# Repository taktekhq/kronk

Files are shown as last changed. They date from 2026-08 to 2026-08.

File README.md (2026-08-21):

# kronk

DIY Raspberry Pi video intercom. Pull the lever, Kronk!

Someone rings the building gate. You see them, talk to them, and buzz them in from your home.

First hardware project, documented in public so anyone can build one.

## Docs

| Doc | Content |
|---|---|
| [Parts](docs/parts.md) | What you need, and what I got |
| [Bill](docs/bill.csv) | What I paid |
| [Gate setup](docs/gate-setup.md) | Setting up `kronk-gate`, step by step |
| [Home setup](docs/home-setup.md) | Setting up the Pi 5 with Home Assistant |
| [Build log](docs/build-log.md) | Progress journal |
| [Architecture](docs/architecture.md) | How it fits together |

## Status

The gate camera is live in Apple Home with audio, recording, and face recognition. The doorbell button and lock relay are on MQTT. Home Assistant entities, HomeKit, and the speaker are next.

## License

[MIT](LICENSE)

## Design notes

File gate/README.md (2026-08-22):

# kronk-gate daemon

Bridges the gate GPIO to MQTT.

| Event | Topic | Payload |
|---|---|---|
| Button press, GPIO27 | `kronk/doorbell` | `ding` |
| Unlock command | `kronk/lock/set` | `UNLOCK` |
| Lock state, retained | `kronk/lock/state` | `UNLOCKED`, then `LOCKED` after the 3s relay pulse on GPIO17 |
| Daemon state, retained | `kronk/status` | `online`, `offline` |

Retained messages on `kronk/lock/set` are ignored and cleared. A retained `UNLOCK` would replay on every reconnect. Publish commands without the retain flag.

## Build

Tag `gate-v*`. The [release workflow](../.github/workflows/release-gate.yml) attaches `kronk-gate-arm64` to the GitHub Release.

Local cross compile:

```
GOOS=linux GOARCH=arm64 CGO_ENABLED=0 go build -trimpath -ldflags "-s -w" -o kronk-gate-arm64 .
```

## Deploy

Create `/home/nizarmah/kronk-gate.env` on the Pi. Single-quote the values, no single quotes inside.

```
KRONK_BROKER='tcp://homeassistant.local:1883'
KRONK_MQTT_USER='kronk-gate'
KRONK_MQTT_PASS='change-me'
```

The daemon resolves `.local` names itself, one mDNS query per connect attempt. The static build cannot use the system resolver, so a plain hostname lookup would die with `no such host`.

It holds the MQTT password, keep it owner-only:

```
chmod 600 ~/kronk-gate.env
```

Download the release binary and unit on the Pi, then enable:

```
curl -Lo kronk-gate https://github.com/taktekhq/kronk/releases/latest/download/kronk-gate-arm64
curl -LO https://raw.githubusercontent.com/taktekhq/kronk/main/gate/kronk-gate.service
chmod +x kronk-gate
sudo mv kronk-gate.service /etc/systemd/system/
sudo systemctl daemon-reload
sudo systemctl enable --now kronk-gate
```

Upgrading: `sudo systemctl stop kronk-gate` first. Writing into the running binary fails with `Text file busy`. Curl, then start the service again.

Manual run instead of the service:

```
set -a; . ~/kronk-gate.env; set +a; ~/kronk-gate
```

## Test

Home Assistant: Settings, Devices and services, MQTT, Configure, listen to `kronk/#`.

- Press the button: `kronk/doorbell` shows `ding`.
- Publish `UNLOCK` to `kronk/lock/set`, retain unchecked: the relay clicks for 3s, `kronk/lock/state` shows `UNLOCKED` then `LOCKED`.
- Stop the service: `kronk/status` shows `offline`.

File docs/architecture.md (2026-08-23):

# Architecture

Working plan, partially built. The [build log](build-log.md) tracks reality.

```
        BUILDING GATE                          APARTMENT
┌─────────────────────────────┐      ┌───────────────────────────────┐
│  Gate unit                  │      │  Indoor unit                  │
│                             │      │                               │
│  Raspberry Pi Zero 2 W      │ WiFi │  Raspberry Pi 5 (4GB)         │
│   ├─ Camera Module 3 NoIR   │◄────►│   ├─ Home Assistant           │
│   ├─ USB mini microphone    │      │   ├─ TDA7266 amp + speaker    │
│   ├─ Doorbell push button   │      │   └─ Microphone (TBD)         │
│   ├─ Relay → gate opener    │      │                               │
│   └─ 12V→5V buck converter  │      │                               │
└─────────────────────────────┘      └───────────────────────────────┘
```

## Software

- `kronk-gate` streams camera video and mic audio with [go2rtc](https://github.com/AlexxIT/go2rtc). Setup in [gate setup](gate-setup.md).
- The Pi 5 runs Home Assistant. Setup in [home setup](home-setup.md).
- Scrypted, a Home Assistant add-on, pulls the gate stream over RTSP and serves the camera to Apple Home as its own accessory. The camera does not go through Home Assistant.
- The HomeKit Bridge exposes the lock to Apple Home. The doorbell rings through Scrypted, a video doorbell on the camera.
- An Apple TV is the Home hub, which enables access over the internet.
- UI: the Apple Home app.
- Recording: HomeKit Secure Video with iCloud+. Apple archives, the Pi streams. OpenCV motion detection in Scrypted gates it.
- Doorbell and lock path: gate GPIO, MQTT, then Home Assistant for the lock and Scrypted for the ring. The GPIO to MQTT leg is the [`kronk-gate` daemon](../gate/README.md).

## Gate unit

Hostname: `kronk-gate`.

| Function | Part |
|---|---|
| Compute | [Pi Zero 2 W](parts.md#gate-unit) |
| Video | [Camera Module 3 NoIR](parts/camera.md) |
| Doorbell | [Push button with LED ring](parts/push-button.md) on GPIO27 |
| Audio in | [USB mini microphone](parts/microphone.md) |
| Gate opener | [5V relay](parts/relay.md) on GPIO17 |
| Power | 12V feed, [buck converter](parts/buck-converter.md) to 5V |

## Indoor unit

| Function | Part |
|---|---|
| Compute | Pi 5 with [27W PSU](parts/power-supply.md) and [Active Cooler](parts/active-cooler.md) |
| Audio out | [TDA7266 amp](parts/amplifier.md) + [50mm speaker](parts/speaker.md) |
| Display / UI | Apple Home app via HomeKit |
| Audio in | TBD |

## Open questions

- Two-way audio.
- Remote viewing through the Apple TV hub is slow, poor over cellular. Candidate fix: a low bandwidth substream in Scrypted.
- Gate unit enclosure and weatherproofing.
- How the relay wires into the existing gate opener, and where the 12V comes from.
- The second Pi Zero 2 W: spare, or a second unit later.
- The building's existing wired doorbell has a button per floor. Tap it for the floors, or add a separate board. Needs a voltage measurement first, those bells often run 8 to 12V AC.
- Multi-tenant support. Out of scope for the first prototype.

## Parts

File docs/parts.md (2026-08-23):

# Parts

What you need to build kronk, and what I got. Prices are in the [bill](bill.csv).

## Gate unit

- Small computer: Raspberry Pi Zero 2 W, no header. I got 2.
- Low light camera: [Raspberry Pi Camera Module 3 NoIR](parts/camera.md), original, not Wide
- Camera cable for the Pi Zero: Raspberry Pi Zero camera cable
- Doorbell button: [metal push button, momentary, 12mm, LED ring](parts/push-button.md)
- Microphone: [USB 2.0 mini microphone](parts/microphone.md)
- Relay for the gate opener: [1 channel 5V relay](parts/relay.md)
- Power: [12V to 5V 3A buck converter](parts/buck-converter.md)
- Microphone adapter: micro USB male to USB-A female (OTG). A plain cable does not work. Getting a UGreen Micro USB Male to USB 2.0 Female Adapter Converter.

From home, not in the [bill](bill.csv):

- Power cable: micro USB to USB-A. I used one I had.
- Power brick with a USB-A port: any charger works. I used an old Samsung one.

## Indoor unit

- Main computer: Raspberry Pi 5, 4GB RAM
- Power supply: [official Raspberry Pi 27W USB-C, EU plug](parts/power-supply.md)
- Cooling: [official Raspberry Pi 5 Active Cooler](parts/active-cooler.md)
- Amplifier: [TDA7266 dual channel](parts/amplifier.md)
- Speaker: [stereo speaker, 50mm, 8 ohm, 3W](parts/speaker.md)
- Home hub for internet access: an Apple TV or HomePod. I used an Apple TV I had.

## Indoor mounting

The indoor unit sits on the wall socket by the main router. No wall screws.

- Socket extender, holds everything: LDNIO Z11, 4 AC outlets
- Pi 5 support: [3D printed saddle](../print/pi5-saddle/README.md) resting on the socket extender and the WiFi extender

From home, not in the [bill](bill.csv):

- WiFi extender for ethernet: Cudy AC1200 mesh (RE1200). I used the one we had.
- 3D printer: Bambu Lab A1 Mini
- Filament: PLA, Basic Black then PLA Tough Jade White

## Storage

- SD card for the Pi 5: Adata microSDXC 64GB, UHS-I Class 10 V10
- SD cards for the Pi Zeros: Adata micro SD 32GB, Class 10. I got 2.
- Card reader: [UGreen 2 in 1 USB-C and USB-A SD/TF reader](parts/card-reader.md)

## Tools and wiring

- Soldering iron: 60W, adjustable temperature
- Solder: activated flux core solder wire, under 1mm diameter. Borrowed from a friend.
- GPIO headers: 40 pin male, single row, 2.54mm pitch. I got 2, one per Pi Zero.
- Jumper wires: DuPont 20cm, 40 piece packs. I got M-M, M-F, and F-F.

Note: the Pi Zero 2 W with pre-soldered header was out of stock, hence the headerless boards, separate headers, and soldering iron.

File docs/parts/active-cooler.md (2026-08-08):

# Raspberry Pi 5 Active Cooler

Official cooler for the Pi 5. Aluminum heatsink with a temperature-controlled blower fan. Push-pin mount, thermal pads pre-applied.

## Specs

- Input: 5V DC via the Pi 5 four-pin fan header
- Fan control: PWM with tachometer feedback
- Max airflow: 1.09 CFM
- Max fan speed: 8000 RPM, plus or minus 15%
- Material: anodized aluminum
- Mount: spring-loaded push pins
- Pi 5 only

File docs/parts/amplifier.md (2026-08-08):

# TDA7266 Dual Channel Audio Amplifier

7W + 7W amplifier module with onboard volume potentiometer and screw terminals for speakers.

## Specs

- Chip: TDA7266
- Channels: 2 (left and right)
- Output: 7W + 7W
- Speaker impedance: 4 to 8 ohm, recommended 5 to 15W
- Supply: 3 to 18V DC
- PCB: 45mm x 33mm
- Terminals: 2-way, 5.08mm pitch

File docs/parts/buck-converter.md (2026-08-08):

# DC/DC Buck Converter 12V to 5V 3A

Steps 12V down to 5V. Synchronous rectification, efficiency 96% or higher. Epoxy sealed, waterproof housing. Non-isolated.

## Specs

- Input: DC 8 to 20V
- Output: DC 5V, 3A, 15W
- Protection: overload, over-current, over-temperature, short circuit, with auto recovery
- Size: 46mm x 27mm x 14mm
- Color: black

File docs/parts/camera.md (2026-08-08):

# Raspberry Pi Camera Module 3 NoIR

12MP camera with a Sony IMX708 sensor and no IR cut filter, so it sees in low light and infrared. Fast autofocus.

## Specs

- 12MP Sony IMX708 back-illuminated stacked CMOS sensor
- High signal-to-noise ratio
- 2D Dynamic Defect Pixel Correction (DPC)
- Phase Detection Autofocus (PDAF)
- QBC Re-mosaic function
- HDR mode up to 3MP output
- Resolution: 4608 x 2592 (11.9MP effective)
- Sensor size: 7.4mm diagonal, pixel size 1.4um x 1.4um
- Diagonal field of view: 75 degrees
- Video modes: 1080p50, 720p100, 480p120
- RAW10 output
- No IR cut filter (NoIR variant)
- CSI-2 data output, I2C fast mode control
- 2-wire serial control for autofocus
- Dimensions: 25 x 24 x 11.5mm
- 200mm ribbon cable, 15 x 1mm FPC connector

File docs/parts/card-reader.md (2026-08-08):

# UGreen 2 in 1 SD/TF Card Reader (CM304 80191)

Compact card reader with both USB-C and USB-A plugs. Used to flash SD cards.

## Specs

- Brand: UGREEN, model CM304
- Input: 1x USB-A, 1x USB-C
- Slots: 1x SD, 1x TF (micro SD)
- USB 3.0, up to 5Gbps
- Transfer speed: up to 170MB/s
- Cards: SD 3.0, micro SD
- Max capacity: 512GB measured, 2TB theoretical
- Works on Windows, macOS, Linux
- Color: black

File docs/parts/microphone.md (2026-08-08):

# USB 2.0 Mini Microphone

Plug-and-play USB microphone with noise cancelling and an illuminated power switch.

## Specs

- Working voltage: 4.5V
- Size: 2cm x 2cm x 0.5cm
- Color: black

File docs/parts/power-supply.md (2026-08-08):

# Raspberry Pi 27W USB-C Power Supply (EU)

Official USB-C PD adapter for the Raspberry Pi 5. Delivers 5V 5A, which unlocks higher USB current for accessories on the Pi 5. Model ELE-DEB-RAA-041.

## Specs

- Total power: 27W
- Input: 100V to 240V AC
- Output profiles: 5V 5A, 9V 3A, 12V 2.25A, 15V 1.8A
- Connector: USB Type-C
- Plug: EU
- Cable: 1.2m, 17 AWG
- Color: white

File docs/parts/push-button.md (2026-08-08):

# Metal Push Button, Momentary, 12mm, LED Ring

Stainless steel waterproof push button with a 12V LED ring. Used as the doorbell.

## Specs

- Type: momentary, push to activate, release to reset
- Rating: 36V 2A
- LED voltage: 12V
- Mounting hole: 12mm
- Total length: 21.3mm, head width 14mm
- LED colors available: white, yellow, pink, blue
- Material: stainless steel, silver finish
- Mount: rubber ring plus hex nut, dust and waterproof
- Contacts: silver-plated copper

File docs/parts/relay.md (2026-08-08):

# Relay 1 Channel 5V

5V relay module with TTL control input. Switches DC or AC loads up to 220V AC.

## Specs

- Control: 5V TTL signal
- Contacts: one normally open, one normally closed
- Power indicator LED and control indicator LED
- Transistor-driven coil, high impedance control pin
- Pull-down on the control pin to prevent false triggering when floating

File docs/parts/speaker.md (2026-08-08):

# Stereo Speaker 50mm 8 ohm 3W

Compact speaker for DIY audio. Paper cone, foam surround.

## Specs

- Rated power: 3W
- Impedance: 8 ohm
- Diameter: 50mm
- Thickness: about 20 to 30mm
- Diaphragm: paper cone
- Surround: foam edge

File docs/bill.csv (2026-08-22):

item | detail | qty | unit_price_usd | total_usd
Raspberry Pi 5 | 4GB RAM | 1 | 210.00 | 210.00
Raspberry Pi Zero 2 W | no header | 2 | 38.00 | 76.00
Raspberry Pi Camera Module 3 NoIR | original not Wide | 1 | 55.00 | 55.00
Raspberry Pi 27W USB-C Power Supply | EU plug ELE-DEB-RAA-041 | 1 | 20.00 | 20.00
Adata microSDXC 64GB | UHS-I Class 10 V10 | 1 | 18.00 | 18.00
UGreen SD/TF card reader | CM304 80191 | 1 | 15.00 | 15.00
Adata micro SD 32GB | Class 10 | 2 | 14.00 | 28.00
Soldering iron | 60W adjustable temperature | 1 | 12.50 | 12.50
LDNIO Z11 socket extender | 4 AC outlets | 1 | 10.00 | 10.00
UGreen Micro USB Male to USB 2.0 Female Adapter Converter | OTG for the microphone | 1 | 7.25 | 7.25
Raspberry Pi 5 Active Cooler | official | 1 | 7.00 | 7.00
DC/DC buck converter | 12V to 5V 3A 15W | 1 | 4.25 | 4.25
Raspberry Pi Zero camera cable |  | 1 | 4.00 | 4.00
Audio amplifier TDA7266 | dual channel DC 3 to 18V | 1 | 4.00 | 4.00
USB 2.0 mini microphone |  | 1 | 3.25 | 3.25
Metal push button switch | momentary 12V 12mm 4 pin | 1 | 2.50 | 2.50
Stereo speaker | 50mm 8 ohm 3W | 1 | 1.50 | 1.50
Wire jumper DuPont 20cm 40pcs | M-M | 1 | 0.90 | 0.90
Wire jumper DuPont 20cm 40pcs | M-F | 1 | 0.90 | 0.90
Wire jumper DuPont 20cm 40pcs | F-F | 1 | 0.90 | 0.90
Relay 1 channel 5V |  | 1 | 0.60 | 0.60
Pin header 40 pin male | single row 2.54mm pitch | 2 | 0.20 | 0.40
TOTAL |  |  |  | 481.95

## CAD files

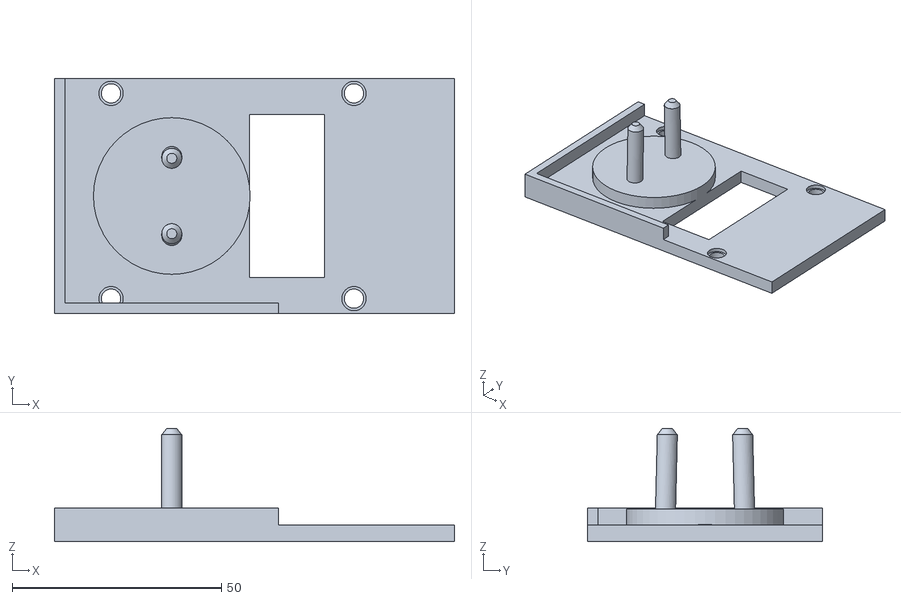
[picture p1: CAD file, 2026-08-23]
print/pi5-saddle/pi5-saddle.stl
95.5 x 56.0 x 27.0

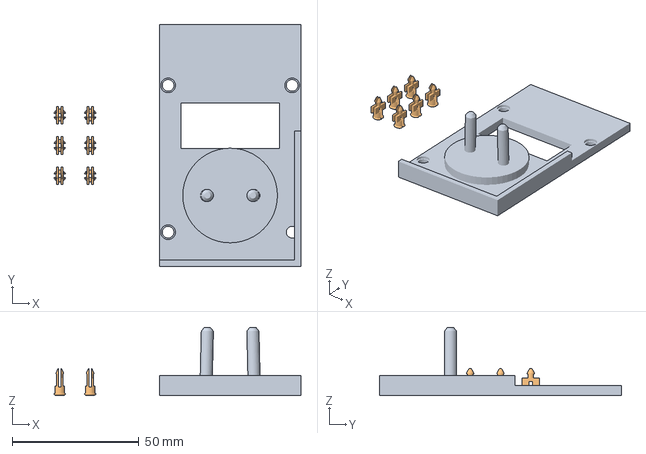
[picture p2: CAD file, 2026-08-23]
print/pi5-saddle/pi5-saddle-and-pegs.3mf
97.6 x 95.5 x 27.0 mm
pi5-saddle.stl
pi5-pegs.stl

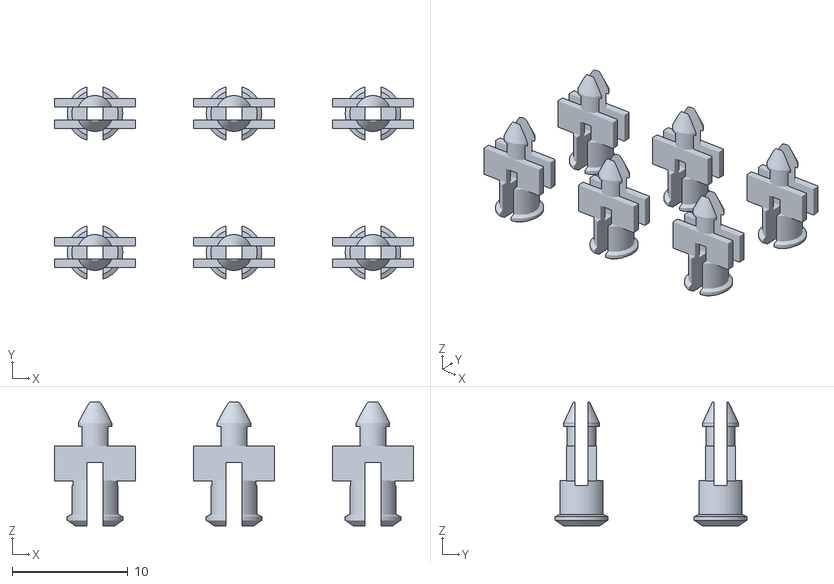
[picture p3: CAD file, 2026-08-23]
print/pi5-saddle/pi5-pegs.stl
31.0 x 16.6 x 10.7

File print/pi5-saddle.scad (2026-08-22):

// Saddle tray for the Raspberry Pi 5, v12. Tool free, no screws.
//
// v13: vented sockets, clean arm, stronger pegs. The whole blind
// sockets trapped air under the entering shaft and broke pegs; the
// sockets are now open through the plate bottom so the air escapes
// below, ring uncut, all four identical. The shaft is shorter than
// the plate, nothing pokes out underneath. The zip tie notches are
// gone, the arm is a uniform rectangle, the plug is the only anchor.
// The peg split no longer runs through the shaft: a solid shaft takes
// the socket press, the split spans only seat and pin where the barb
// needs to flex.
//
// v10: the v8 prongs pulled out too easily, 4.5 wide and only 8mm past
// the socket face. Now they match the European convention, 4.8 wide
// with 19mm engagement, and lean toward each other like a Europlug's
// converging pins so the socket bends them straight and grips.
//
// v9: snap pegs. The v5 pegs sat loose in their sockets and the Pi
// lifted off freely. The pegs are now split snap pins like the Pi
// active cooler's: the barbed tip squeezes through the board's hole
// and clicks open above it, and the fatter split shaft squeezes snug
// into the saddle socket. Remove the board with a firm straight pull,
// or pinch the tips.
// Plugs into the top socket of the LDNIO Z11 socket extender and
// carries the Pi over it and the Cudy AC1200 (RE1200) beside it.
//
// v8: the plug carries everything. Two solid prongs on a round base,
// shaped like a plug face, enter the cube's top socket; the base nests
// in the round well, the contacts grip the prongs. The Cudy foot is
// gone, the arm just cantilevers over it. The skirt walls are short
// alignment guides now, left and room side only. SAFETY: prongs and
// base are solid plastic and must stay that way, no metal, no foil,
// no hollow prongs.
//
// Pegs: separate press-in parts. The saddle top is flat, so it prints
// upside down, top face on the bed, no supports, no bridges. Press
// the four pegs into the Pi's mounting holes first, then drop board
// and pegs into the saddle's sockets; the board's weight traps the
// flanges.
//
// Two parts from this one file:
//   openscad -o pi5-saddle.stl pi5-saddle.scad            (print ready, flipped)
//   openscad -D 'part="pegs"' -o pi5-pegs.stl pi5-saddle.scad
// Set part="assembly" to preview everything upright with pegs seated.
//
// MEASURE, top socket of the cube: hole spacing (prong_gap), well
// depth to the socket face (well_depth), well diameter (base_d must
// stay under it), and whether the two holes line up wall-to-room
// (prong_along_y) or along the wall.
//
// Print: saddle exactly as the STL opens, flat face on the bed, no
// supports. Pegs standing, add a brim. 0.2mm, PLA, dry the spool.
//
// Fit tuning, one variable per reprint: cube grip, clr. Pin in the
// board holes, pin_d. Peg in the saddle, socket_d. Prong grip in the
// socket, prong_d. Base in the well, base_d.

part = "saddle";  // "saddle" | "pegs" | "assembly"

clr = 0;          // extra clearance around the cube; the printed 51.0
                  // cavity fit the 51 cube well, raise only if a
                  // reprint runs tight
wall = 2.5;       // skirt wall thickness
plate_t = 4;      // tray plate thickness

// LDNIO Z11, measured 5.1cm each way, fit confirmed on the wall
z11 = 51;         // cube top, both directions
skirt_drop = 4;   // short guide walls; the prongs do the locking

// Cudy AC1200
arm_len = 42;     // arm past the cube face, ends at the board's edge,
                  // cantilevers over the Cudy, no foot

// prongs into the cube's top socket, solid plastic only.
// European convention: pins are 4.8 thick and engage 19 deep, the
// socket's grip springs sit well behind the face. The prongs also
// lean toward each other like a Europlug's converging pins: the
// socket bends them straight and the springback grips.
prong_d = 4.8;    // standard pin diameter; drop to 4.6 if insertion fights
prong_gap = 19;   // hole spacing, center to center, confirmed by v8
well_depth = 4;   // cube top surface down to the socket face, measured
engage = 19;      // standard pin engagement below the socket face
prong_lean = 0.5; // each tip pulls this much toward center; more lean,
                  // more grip; 0 is a parallel Schuko pin
prong_along_y = true; // holes line up wall-to-room, confirmed by v8
base_d = 37.4;    // round base fills the measured 38 well, 0.6 clearance
base_h = 3.8;     // almost the full 4 well depth; 0.2 shy so the plate
                  // still seats on the cube top, the base bears just after

// Raspberry Pi 5, long side parallel to the wall
pi_l = 85;
pi_w = 56;
hole_dx = 58;     // official mounting hole pattern, holes 3.5 from edges
hole_dy = 49;

// pegs, printed separately. Snap pins like the active cooler's: a
// split runs the whole peg, the barbed tip squeezes through the
// board's hole and clicks open above it. The flex lives in the long
// split, which keeps PLA inside its elastic range.
pin_d = 2.5;      // pin through the board's 2.7 holes
pcb_t = 1.6;      // Pi board thickness, the barb catches just above
barb_d = 3.1;     // barb over the 2.7 hole, 0.2 catch per side
barb_h = 0.3;     // the flat catch ledge
tip_h = 1.8;      // cone above the barb, the squeeze-in lead
seat_l = 7;       // seat bar the board rests on, along the split
seat_w = 2.6;     // seat bar width
seat_h = 3;       // air under the board, clears the microSD card
split_w = 1.1;    // the split; the halves flex toward each other
shaft_d = 4.2;    // shaft into the saddle socket, snug, and the split
                  // lets it squeeze in
shaft_h = 3.7;    // fills most of the through socket, 0.3 shy of
                  // the plate bottom, never pokes out
socket_d = 4.3;   // socket through the plate, open at the bottom so
                  // the air escapes; the shaft is shorter than the
                  // plate and never pokes out underneath

eps = 0.01;
$fn = 48;

// derived
plat_x0 = -(clr + wall);          // platform outer left edge
plat_y0 = -(clr + wall);          // platform outer wall-side edge
plat_y1 = z11 + clr + wall;       // platform outer room-side edge
arm_x0 = z11 + clr;               // arm starts at the cube's right face
arm_x1 = arm_x0 + arm_len;        // arm end

pi_x0 = 7.5;                      // board left edge
pi_y0 = z11/2 - pi_w/2;
holes = [[pi_x0 + 3.5, pi_y0 + 3.5], [pi_x0 + 3.5 + hole_dx, pi_y0 + 3.5],
         [pi_x0 + 3.5, pi_y0 + 3.5 + hole_dy],
         [pi_x0 + 3.5 + hole_dx, pi_y0 + 3.5 + hole_dy]];

module saddle() {
    difference() {
        union() {
            // one full width plate, platform and arm, flat top
            translate([plat_x0, plat_y0, 0])
                cube([arm_x0 - plat_x0, plat_y1 - plat_y0, plate_t]);
            translate([arm_x0 - eps, pi_y0, 0])
                cube([arm_x1 - arm_x0 + eps, pi_w, plate_t]);
            // short guide walls, left and room side. Wall side stays
            // open, the outlet's raised edge lives there. Right stays
            // open for the Cudy.
            translate([plat_x0, plat_y0, -skirt_drop])
                cube([wall, plat_y1 - plat_y0, skirt_drop + eps]);
            translate([plat_x0, plat_y1 - wall, -skirt_drop])
                cube([z11 - plat_x0, wall, skirt_drop + eps]);
            // round base nesting in the socket well, prongs from its
            // face, the whole thing shaped like a plug: hold-down and
            // lateral lock. Solid plastic, cone tips for the lead-in.
            translate([z11/2, z11/2, -base_h])
                cylinder(d = base_d, h = base_h + eps);
            for (s = [-1, 1]) {
                px = z11/2 + (prong_along_y ? 0 : s*prong_gap/2);
                py = z11/2 + (prong_along_y ? s*prong_gap/2 : 0);
                bx = z11/2 + (prong_along_y ? 0 : s*(prong_gap/2 - prong_lean));
                by = z11/2 + (prong_along_y ? s*(prong_gap/2 - prong_lean) : 0);
                zb = -(well_depth + engage);
                hull() {
                    translate([px, py, -1]) cylinder(d = prong_d, h = 1 + eps);
                    translate([bx, by, zb + 1.5]) cylinder(d = prong_d, h = 0.5);
                }
                translate([bx, by, zb]) cylinder(d1 = 2.4, d2 = prong_d, h = 1.5 + eps);
            }
        }

        // peg sockets, straight through the plate: the trapped air
        // that broke pegs escapes out the bottom
        for (h = holes)
            translate([h[0], h[1], -eps])
                cylinder(d = socket_d, h = plate_t + 2*eps);

        // vent window under the board, beside the base
        translate([44, z11/2 - 19.5, -eps]) cube([18, 39, plate_t + 2*eps]);

    }
}
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

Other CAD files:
print/pi5-saddle/pi5-saddle.scad

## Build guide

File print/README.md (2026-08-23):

# Prints

3D printed parts, one directory per part. Printer: Bambu Lab A1 Mini.

- [pi5-saddle/](pi5-saddle/README.md): tray for the Raspberry Pi 5, plugs into the LDNIO Z11 socket extender

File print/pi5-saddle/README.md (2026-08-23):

# Pi 5 saddle

Filament: PLA, currently PLA Tough Jade White; the flexing barbs like the tougher blend.

[pi5-saddle.scad](pi5-saddle.scad), rendered to [pi5-saddle.stl](pi5-saddle.stl) and [pi5-pegs.stl](pi5-pegs.stl). [pi5-saddle-and-pegs.3mf](pi5-saddle-and-pegs.3mf) is the ready Bambu Studio project, both parts on one plate.

Tray for the Raspberry Pi 5. Plugs into the top socket of the LDNIO Z11 socket extender and cantilevers over the Cudy AC1200. No wall screws, no board screws, tool free. Two parts: the saddle, and press-in pegs.

v14. The plug carries everything: two solid prongs on a round base, shaped like a plug face, enter the top socket. The prongs follow the European convention, 4.8mm thick with 19mm engagement past the socket face, and lean 0.5mm toward each other like a Europlug's converging pins, so the socket bends them straight and the springback grips. The base fills the measured 38mm well, 0.2 shy of its 4mm floor, so the plate seats on the cube and the base bears just after. No foot on the Cudy, the arm cantilevers over it. The skirt walls are 4mm alignment guides on the left and room sides only. The top is flat, so the saddle prints upside down with no supports and no bridges.

The pegs are double-ended rivets, push to click at both ends. The bottom barb clicks into a counterbore hidden in the plate's underside, flush, nothing protruding; the top barb squeezes through the Pi's mounting hole and clicks open above it, like the active cooler's pins. The bore is a clearance fit, nothing rubs on the way in; friction fits between printed parts are gone for good, printed holes shrink and fought every press. Two crossed splits give each barb its own long flex.

Safety: prongs and base are solid plastic, the same idea as a child safety blanking plug. Keep them that way. No metal, no foil, no hollow prongs, and if a prong ever snaps off inside the socket, pull it out with pliers before replugging anything.

Top socket numbers, all confirmed on the wall: holes 19 apart lined up wall-to-room, well 38 wide and 4 deep to the socket face.

Print:

- Saddle: exactly as the STL opens, flat face on the bed. Needs nothing.
- Pegs: standing as the STL opens, six of them, four plus two spares. Supports ON, tree slim: the slicer builds a small disk under each peg's tiny foot, which is what keeps them on the bed. Clean the support film off each foot before inserting.
- The 3mf has all of this set already.
- 0.2mm layers, PLA. Dry the spool: 45 to 50C oven for 4 to 6 hours, keep it bagged after.
- Regenerate after edits:
  `openscad -o pi5-saddle.stl pi5-saddle.scad`
  `openscad -D 'part="pegs"' -o pi5-pegs.stl pi5-saddle.scad`

Assembly:

- Press the four pegs into the saddle's sockets, straight down with a thumb on top, until the bottom barb clicks into the plate. They slide free and end with a click, no force fighting you.
- Line the prongs over the top socket's holes and push the saddle straight down until the plate sits on the cube. The arm floats over the Cudy.
- Line the board's mounting holes over the peg tips and press down until the barbs click through. The seat bars keep 3mm of air under the board for the microSD card.
- Pi off: a firm straight pull, or pinch the peg tips and lift corner by corner; the pegs stay riveted in the saddle. Peg out: pull its seat bar firmly upward, the bottom barb ramps free. Saddle off: pull straight up, it unplugs.

Fit:

- Cube grip: tune `clr`. Board click too weak or too fierce: tune `barb_d`. Peg click into the saddle too weak or too fierce: tune `anchor_d`. Saddle pulls out too easily: raise `prong_lean`. Insertion fights: lower `prong_lean` or `prong_d`. Base in the well: tune `base_d`. One variable per reprint.

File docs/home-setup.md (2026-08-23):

# Indoor Unit Setup

Steps to set up the [Pi 5](parts.md#indoor-unit). Work in progress.

## Home Assistant

1. Install the [Active Cooler](parts/active-cooler.md).
2. Flash the SD card with Home Assistant.
3. Boot with ethernet and a solid power outlet, then finish onboarding. You can watch status and logs during setup.
   On WiFi instead: put the network details on a FAT32 USB stick named CONFIG. The stick has to stay plugged in, WiFi drops without it.
   `http://homeassistant.local:4357` shows Home Assistant's health while the main page is still loading.
4. Update the software and reboot.

## Apple Home

An Apple TV signed into the same account becomes the Home hub automatically, which gives access over the internet.

Two paths into Apple Home, both further down: the camera and doorbell pair from Scrypted, the lock through the [YAML HomeKit Bridge](#lock-in-apple-home). Don't add a HomeKit Bridge from the integrations UI, a second bridge doubles the lock.

Keep Apple devices out of Home Assistant. The Apple TV integration loops back through the HomeKit Bridge and fills Apple Home with ghost duplicates.

## Gate camera through Scrypted

The camera does not go through Home Assistant. Scrypted serves it to Apple Home directly. It cuts the latency of Home Assistant's HomeKit Bridge repackaging the stream.

1. Install the Scrypted add-on. Add the repository from the [install guide](https://github.com/koush/scrypted/wiki/Installation:-Home-Assistant-OS), then install.
2. Enable everything in the add-on controls: start on boot, watchdog, auto update, show in sidebar. Then start Scrypted.
2. In Scrypted, install the `@scrypted/homekit` and `@scrypted/rtsp` plugins.
3. Add the camera with the go2rtc RTSP URL: `rtsp://kronk-gate.local:8554/gate`.
4. Skip the Scrypted Home Bridge. Enable the HomeKit extension on the camera itself, so it pairs in Apple Home as its own accessory. Scan its QR code in the Home app.

Stream settings:

- RTSP Parser: Scrypted (TCP). The stream crosses WiFi, and UDP drops show as gray smears and corrupt frames.
- Prebuffered Streams: on. Scrypted keeps a rolling buffer so HomeKit opens instantly, and it feeds HomeKit Secure Video motion events.
- Keep the Rebroadcast, Snapshot, and WebRTC plugins on. Rebroadcast drives the prebuffer, Snapshot feeds the Home app tile.
- Detected stream should read 1920x1080 around 2000Kb/s, h264/opus, 4 second keyframe interval. That matches everything Scrypted recommends.

If re-adding the camera says it is part of a different home, use Reset Pairing in the camera's HomeKit section to get a fresh QR code.

## MQTT broker

The [`kronk-gate` daemon](../gate/README.md) publishes the doorbell and lock over MQTT.

1. Install the Mosquitto broker add-on (Settings, Apps) and start it.
2. Create a Home Assistant user `kronk-gate` for the daemon. Mosquitto accepts Home Assistant credentials.
3. Add the MQTT integration. It finds the add-on broker.
4. Put the credentials in the daemon's env file on `kronk-gate`. Broker URL: `tcp://homeassistant.local:1883`. The daemon resolves `.local` over mDNS itself, details in the [daemon README](../gate/README.md#deploy).

Lock and doorbell entities in `configuration.yaml`:

```yaml
mqtt:
  lock:
    - name: Gate
      command_topic: kronk/lock/set
      state_topic: kronk/lock/state
      payload_unlock: UNLOCK
      state_locked: LOCKED
      state_unlocked: UNLOCKED
      availability_topic: kronk/status
  event:
    - name: Gate doorbell
      state_topic: kronk/doorbell
      event_types: [ding]
      device_class: doorbell
      value_template: '{"event_type": "{{ value }}"}'
      availability_topic: kronk/status
```

The Lock button does nothing by design. The relay is momentary, the gate locks itself after the pulse.

The event entity feeds automations and the logbook. Rings reach Apple Home through Scrypted instead.

## Lock in Apple Home

The HomeKit Bridge cannot expose event entities, and a UI bridge next to a YAML bridge doubles the lock. One YAML bridge, in `configuration.yaml`:

```yaml
homekit:
  - name: Kronk Bridge
    filter:
      include_entities:
        - lock.gate
```

Restart Home Assistant, then scan the pairing QR code from the sidebar notification in the Home app.

## Doorbell through Scrypted

The gate button rings Apple Home as a video doorbell on the camera, snapshot in the notification.

1. Create a Home Assistant user `scrypted` for the broker, local only, not admin.
2. In Scrypted, install the `@scrypted/mqtt` and `@scrypted/dummy-switch` plugins.
3. MQTT plugin, Add New: name `Gate doorbell button`, template `button.ts`, subscription URL `mqtt://127.0.0.1:1883` with no path, the `scrypted` credentials. Credentials go on the device, the plugin's general settings are ignored. Restart the MQTT plugin after creating it, settings only load when the script runs.
4. The script pulses, the daemon sends `ding` with no release:

   ```ts
   mqtt.subscribe({
       'kronk/doorbell': value => {
           if (value.text !== 'ding') return;
           device.binaryState = true;
           setTimeout(() => device.binaryState = false, 3000);
       },
   });
   mqtt.handleTypes(ScryptedInterface.BinarySensor);
   ```

   Press the button: the device Console logs the message.
5. On the camera, Extensions: enable Custom Doorbell Button, pick the button, then toggle the extension off and on. The selection only registers when the extension starts. If the device type still says Camera, set it to Doorbell by hand.
6. Camera, HomeKit: Reset Pairing. Remove the camera in the Home app, add it back with the new QR code, it pairs as a doorbell. Re-enable Stream and Allow Recording, HKSV settings reset with the pairing.

## Recording (HomeKit Secure Video)

HKSV needs iCloud+, an online home hub, and the camera exposing a motion sensor. Without motion, the Home app hides the Recording section entirely.

1. In Scrypted, install `@scrypted/objectdetector` and `@scrypted/opencv`. The detector is the framework, OpenCV is a light engine, enough to gate HKSV for one camera.
2. On the camera, enable the OpenCV Motion Detection extension. Defaults are fine. Leave FFmpeg Audio Detection off, a street-facing mic would trigger it constantly.
3. Keep Prebuffer on. HKSV uses it for pre-motion footage.
4. HomeKit extension, Reset Pairing. In the Home app, remove the stale camera, add the accessory with the new QR code, and pick Stream and Allow Recording during setup.

Recording options and Face Recognition appear in the camera's settings. Activity zones are drawn in the Home app, not Scrypted.

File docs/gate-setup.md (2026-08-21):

# Gate Unit Setup

Steps to set up `kronk-gate`, the [Pi Zero 2 W](parts.md#gate-unit) at the gate. Work in progress.

## Camera

The Pi Zero's camera connector is smaller than standard, so the [NoIR camera](parts/camera.md) needs the Pi Zero camera cable.

1. Open the connector latches on the camera and the Pi.
2. Swap the camera's standard cable for the Pi Zero cable.
3. Close the latches.

Verify:

```
rpicam-hello --list-cameras
```

Should print `imx708`. Test photo:

```
rpicam-still -o first-look.jpg
```

## Video stream

[go2rtc](https://github.com/AlexxIT/go2rtc) streams the camera.

Download it on the Pi:

```
curl -Lo go2rtc https://github.com/AlexxIT/go2rtc/releases/latest/download/go2rtc_linux_arm64 && chmod +x go2rtc
```

Create `go2rtc.yaml` from [gate/go2rtc.yaml](../gate/go2rtc.yaml). The name matters: go2rtc ignores `go2rtc.yml`.

The video line targets what HomeKit and Scrypted recommend: 1920x1080 at 25fps, 2Mb/s, and `--intra 100` for a keyframe every 4 seconds (25fps x 4).

Run `./go2rtc`, open `http://kronk-gate.local:1984`, and click the `gate` stream. Live video in the browser. Use the WebRTC stream, it is much faster than the default. The stream's `info` link lists every track and codec, the first stop when something is off.

## Audio

ffmpeg feeds the audio source in [gate/go2rtc.yaml](../gate/go2rtc.yaml):

```
sudo apt install -y ffmpeg
```

To test without a mic, use a 440Hz sine as the second `exec` source:

```
- exec:ffmpeg -re -f lavfi -i sine=frequency=440:sample_rate=16000 -c:a aac -f adts -
```

The tone is AAC, so it plays over MSE but not WebRTC in the browser. WebRTC only carries Opus audio.

For the real [microphone](parts/microphone.md), plug it in through the OTG adapter, then find its card number:

```
arecord -l
```

Mine showed as card 0, USB PnP Sound Device. `vc4-hdmi` is the Pi's HDMI audio output, not the mic.

Raise the capture gain, it defaults very low. In `alsamixer`: F6 to pick the USB card, F4 for capture view, raise Mic to about 85. 100 clips into static. Persist it:

```
sudo alsactl store
```

The audio source in [gate/go2rtc.yaml](../gate/go2rtc.yaml) uses go2rtc's native ffmpeg device syntax, streaming Opus with a volume boost:

```
- ffmpeg:device?audio=plughw:0,0#audio=opus#raw=-af volume=24dB
```

Opus because that is what HomeKit and Scrypted want. Piping AAC, mulaw, or ogg out of an `exec:ffmpeg` line does not work, go2rtc shows the producer as a bare url with no audio track.

If the mic is silent, isolate mic vs pipeline by recording straight from ALSA:

```
arecord -D plughw:0,0 -f S16_LE -r 16000 test.wav
```

## Relay

The [relay](parts/relay.md) has two sides. The 3 pin control side connects to the Zero. The 3 screw terminals, COM, NO, NC, switch the gate opener circuit and stay empty until that wiring session. The opener goes on COM and NO: normally open keeps the gate locked if power drops.

Three F-F jumpers on the control side:

| Relay | Zero physical pin | Why |
|---|---|---|
| VCC | 2 | 5V for the relay coil |
| GND | 6 | shared ground |
| IN | 11 (GPIO17) | the control signal |

Counting pins: hold the board SD card up with the header on the right. Pin 1 is top left, pin 2 top right, odds run down the left, evens down the right.

Colors: red for VCC, black for GND, a bright color for signal.

Test with nothing on the screw side:

```
sudo apt install -y python3-gpiozero
python3 -c "from gpiozero import OutputDevice; import time; r=OutputDevice(17); r.on(); time.sleep(2); r.off()"
```

The relay clicks on, then off. If it is already energized at boot, the board is active low and the signal needs inverting in software.

## Doorbell button

The [button](parts/push-button.md) has four terminals: two are the switch contacts, two are the 12V LED ring. The LED stays unconnected for now.

Two jumpers on the switch contacts, any order:

| Button | Zero physical pin |
|---|---|
| switch contact | 13 (GPIO27) |
| switch contact | 14 (GND) |

F-F jumpers if the sockets grip the lugs, or M-F with the male pin twisted around the terminal for a desk test. Solder before mounting outside, a loose contact means phantom rings.

Test:

```
python3 -c "from gpiozero import Button; b=Button(27); b.wait_for_press(); print('DING')"
```

Press the button and DING prints.

## Run as a service

Install [gate/go2rtc.service](../gate/go2rtc.service) so go2rtc always runs:

```
sudo cp go2rtc.service /etc/systemd/system/go2rtc.service
sudo systemctl daemon-reload
sudo systemctl enable --now go2rtc
systemctl status go2rtc
```

Status should say active (running). Reboot to confirm the stream survives.

Day to day:

```
sudo systemctl restart go2rtc
systemctl status go2rtc
journalctl -u go2rtc -f
```

## Doorbell and lock daemon

The `kronk-gate` daemon bridges the button and relay to MQTT. Build, deploy, and test steps in [gate/README.md](../gate/README.md).

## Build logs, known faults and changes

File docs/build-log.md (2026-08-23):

# Build Log

Dated journal. Newest first.

## 2026-08-23: Lock and doorbell in Apple Home

- Added the lock and doorbell event entities in `configuration.yaml`. Both live, `lock.gate` read the retained `LOCKED` from the broker.
- The HomeKit Bridge UI has no event domain, an event entity cannot be exposed as an accessory. Replaced the UI bridge with a YAML bridge, `linked_doorbell_sensor` hung the doorbell on the lock.
- The UI bridge and the YAML bridge both exposed the lock, two locks in Apple Home grouped into one accessory. Deleted the UI bridge, it carried nothing else.
- Moved the ring to Scrypted for video in the notification: MQTT plugin button subscribed to `kronk/doorbell`, Custom Doorbell Button extension on the camera, re-paired as a video doorbell.
- Three snags. The MQTT device connects with null credentials until the plugin restarts, credentials go on the device not the plugin. The doorbell button selection only registers when the extension starts, toggle it off and on. The button script must pulse the state back to false, the daemon sends no release.
- Dropped `linked_doorbell_sensor` from the YAML bridge, one ring per press.
- End state: unlock and ring in Apple Home, ring carries the camera snapshot. Press to notification runs about a second.

## 2026-08-22: MQTT live, gate daemon connected

- Installed the Mosquitto broker app on Home Assistant, created the `kronk-gate` user, added the MQTT integration.
- Deployed the daemon on `kronk-gate` from the `gate-v0.1.0` release, curl straight onto the Pi.
- First connect failed. The static binary skips mDNS, and the router's DNS knows no `.local` names.
- The daemon now resolves `.local` itself, one multicast query per connect attempt. Released as `gate-v0.1.1`.
- Upgrade gotcha: the running binary cannot be overwritten, `Text file busy`. Stop the service, curl, start.
- Daemon connected: `resolved homeassistant.local to 192.168.1.134`, then `connected`.

Next: listen test on `kronk/#`, the lock and doorbell entities, HomeKit Bridge.

## 2026-08-22: v5 printed, then plugged in, v10

- Printed v5, saddle upside down with no supports, pegs standing. Much better print, much better fit.
- It wobbles on the wall: the wall-side skirt hits the outlet's raised edge between the cube and the wall, which levers the saddle up and keeps the arm off the Cudy.
- v6: the wall-side skirt is gone, nothing extends wallward below the plate anymore. A 30mm boss under the plate drops into the round socket well on the cube's top face and keys the saddle laterally instead. Skirt stays on the left and room sides.
- v7, before printing v6: the boss became two solid prongs that plug into the cube's top socket, the one the saddle covers anyway, like a child blanking plug. The socket's contacts grip them, hold-down and lateral lock in one move. Solid plastic, no metal, ever.
- Removed the antenna notches, the splayed antennas never reach the arm.
- v8: the plug carries everything. The prongs got a round base that nests in the socket well like a real plug face. The Cudy foot is gone, the arm just cantilevers over it and ends at the board's edge. The skirt walls shrank to 4mm alignment guides and lost their tie slots.
- The v5 pegs sat loose in their sockets and the Pi lifted off with no resistance. v9 pegs are snap pins like the Pi active cooler's: a split runs the whole peg, the barbed tip squeezes through the board's hole and clicks open above it, the fatter split shaft squeezes snug into the socket. The round flange became a seat bar along the split so the halves stay thin and PLA flexes instead of snapping.
- Printed the v8 saddle and v9 pegs. The saddle plugs in, hole spacing and orientation confirmed, but it pulls out too easily: the prongs were 4.5 wide and reached only 8mm past the socket face. Real pins are 4.8 wide and engage 19mm, where the grip springs sit.
- v10 prongs match the European convention, 4.8 by 19, and lean 0.5mm toward each other like a Europlug's converging pins, the socket bends them straight and the springback grips.
- Measured the top socket well: 38 wide, 4 deep to the socket face, not the guessed 9. The base grew to 37.4 by 3.8, filling the well 0.2 shy of its floor, so the plate seats on the cube and the base bears just after. The prongs shortened to match the real depth.
- Tested the v9 pegs: snug in the saddle sockets and they click into the Pi's holes properly. One peg died to a too-hard squeeze, a spare took its place.
- Printed the v10 saddle, 16g, 40 minutes. Plugged it in: perfect fit, locked in. The full-size converging prongs grip in the socket, the base fills the well, the plate seats flat on the cube. The saddle is done.
- The snap pegs have a flaw: two of the Pi's four mounting holes are covered above, the barb has nowhere to click open, and forcing it breaks the peg. Both spares gone. The two open holes take the pegs perfectly, easy in and snug.
- Mounted the Pi on the saddle with the surviving pegs, power and ethernet connected. Everything holds. The power corner is live.
- Known issue, fix later: pegs that work on the covered holes. The plan is identical split expansion pins that grip inside the bore instead of clicking open above it.
- Correction, from the CAD screenshots: the Pi's holes were never covered and the pegs were never the problem. The hard "holes" were the saddle's peg sockets. The two sockets the arm's zip tie notches happened to cut open took pegs easily and held snug; the two whole sockets were too stiff, trapped air under the shaft, and broke pegs during insertion. The accident was the better design.
- v13: the sockets now run straight through the plate, open at the bottom, so the trapped air escapes below instead of fighting the shaft. The ring stays whole, all four sockets identical, and the shaft is shorter than the plate so nothing pokes out underneath. The zip tie notches are gone, the arm is a uniform rectangle, the plug is the only anchor.
- Made the pegs stronger: the split no longer runs through the shaft. A solid shaft takes the socket press, the split spans only the seat and pin where the barb needs its flex. One more peg died to the old air pocket during install, the Pi rides on three of four meanwhile.
- Lengthened the peg shafts from 2.9 to 3.7, the through sockets made the room: deeper seat, straighter peg, still 0.3 shy of the plate bottom.
- Saved the Bambu Studio project with both parts and the working settings.
- Printed v13: impossible to press in. Printed holes shrink, and the solid shaft that was meant to be stronger cannot give the way the old split one did. Friction fits between printed parts are done.
- v14: the pegs are double-ended rivets. The bore opened to a clearance fit, nothing rubs, and each end clicks: a bottom barb into a counterbore hidden in the plate's underside, flush, and the top barb through the Pi's hole as before. Two crossed splits, one per barb, each with a long PLA-safe flex. Push to click at both ends, pull the seat bar to free a peg.
- Dropped the stale 3mf, re-export after v14 proves out.
- Sliced v14 with PLA Tough, Jade White: tougher, more ductile, kinder to the flexing barbs than Basic PLA. Saved the project file: [print/pi5-saddle/pi5-saddle-and-pegs.3mf](../print/pi5-saddle/pi5-saddle-and-pegs.3mf). Print started, 16g, 44 minutes.
- First v14 print failed: the pegs stand on two slivers of foot, they came off the bed and strung. Tree supports fixed it, the slicer builds a small disk under each foot. Reprinted, perfect. The working project file is saved, supports on for the pegs.
- The v14 rivets pass: pegs click into the saddle easily and pull back out just as cleanly. Both ends click, nothing fights, nothing breaks. The peg saga is over.

Next: Pi onto the new pegs on the wall, then back to MQTT.

## 2026-08-21: First saddle print failed, redesigned to v5

- Printed the v1 saddle. 0.2mm PLA, no supports, 43 minutes. Heavy stringing, and the bridged underside printed badly.
- Fit test on the wall. The Z11 side is right, the skirt seats well on the cube.
- The Cudy side is wrong. The antennas stand near the Cudy's far end, not along the arm's sides, so the flares are useless and the arm reaching for the far edge ends at the antennas with the foot never touching the surface 10mm below.
- The Pi mount is wrong. The pocket side hits the power button, the latch side hits the ethernet and USB ports, the latch never clicked.
- A top photo decoded the Cudy: the antennas hinge at the sides of the body near its far end and splay outward at body level, one toward the wall, one toward the room. They never rise through the arm. The hinge fronts sit about 30mm from the cube face. The cube is 51mm each way, not 50.
- Redesigned as v4. The antenna flares, chamfers, and through slots are gone. Open notches on the arm's side edges span the hinge zone, room for the paddles raised or splayed, no hinge load. The foot lands on the clear flat with its far face against the hinge fronts, which stops the saddle sliding off the open side; the left skirt wall stops the other direction.
- The edge grips are gone. The Pi mounts by its four mounting holes, the only spots on a Pi 5 guaranteed free of parts. Nothing touches the board edges.
- Cube cavity kept at the printed 51.0 that fit well.
- The photo is scaled off the 51mm cube, good for layout, not for lengths: the Cudy top sits lower and reads about 15 percent short. The tape numbers stand where they conflict: 54 protrusion, 16 hump, 10 drop, 58 width. hinge_x is the one photo length the fit depends on, set to 30, ruler check pending.
- Split the pegs into separate press-in parts as v5. The saddle's top is flat now, so it prints upside down on the bed, no supports and no bridges, which removes what failed in print one. The pegs print standing, four plus two spares. Press them into the board first, then drop board and pegs into sockets in the plate; the board's weight traps the flanges.
- The stringing was moisture, dry the spool.

Next: check hinge_x with a ruler, print the saddle and the pegs, test fit.

## 2026-08-21: Power corner up, Pi 5 saddle designed

- Bought the LDNIO Z11 socket extender, 4 AC outlets, and plugged it into the wall socket by the main router.
- Plugged the Cudy AC1200 mesh WiFi extender into the Z11's right face. It bridges the Pi 5 to the network over ethernet.
- The Pi 5, its power supply, and the ethernet cable still need a home. Decided against a wall box: no screws in the wall, no closed box around a hot Pi. Instead a printed saddle that rests on the Z11 and the Cudy.
- The web has no body dimensions for the Z11 or the indoor AC1200. Measured by hand: Z11 cube 50x50x50, sticking 70mm from the wall. Cudy protrudes 54mm from the Z11 face, a 16mm plug hump then a 58x38 flat top, 10mm below the Z11 top. Antennas flank the flat top, 58mm gap between them.
- Designed the saddle: [print/pi5-saddle.scad](../print/pi5-saddle/pi5-saddle.scad). A platform caps the Z11 with a skirt gripping three sides, a 54mm arm passes between the antennas, a foot steps down 10mm onto the Cudy flat. Vent windows under the board, zip tie slots as fallback anchors.
- No screws anywhere. The Pi slides onto the tray: edge ribs lift the board 3mm, side guides set it straight, two pockets catch the left edge, a latch clicks behind the right edge. Press the latch, slide right, the Pi is out.
- Flared notches on the arm sides nest around the antenna bases as lateral guides. No vertical load on the antennas, they are hinged plastic and would droop.
- One part, prints upright, no supports, fits the A1 mini bed. PLA Basic Black.

Next: print, test fit, adjust one variable and reprint if needed.

## 2026-08-21: Doorbell and lock on MQTT

- Wrote the `kronk-gate` daemon in Go: the GPIO27 button publishes `kronk/doorbell`, `UNLOCK` on `kronk/lock/set` pulses the GPIO17 relay for 3s and publishes `kronk/lock/state`. Source and topics in [gate/README.md](../gate/README.md).
- Added a release workflow that builds `kronk-gate-arm64` on `gate-v*` tags, and a CI workflow that builds on pull requests.
- Review hardened the lock logic: retained commands are ignored and cleared so a reconnect cannot replay an unlock, the relay actuates before any state publish, state follows the actual pin writes, publishes are bounded at 5s, and shutdown waits out an in-flight pulse then forces the relay low.
- Tagged `gate-v0.1.0`. First release, `kronk-gate-arm64` attached.

Next: Mosquitto on the Pi 5, MQTT lock and doorbell entities in Home Assistant, HomeKit.

## 2026-08-09: Relay wired, Kronk gets hands

- Wired the relay's control side to `kronk-gate` with three F-F jumpers: VCC to pin 2 (5V), GND to pin 6, IN to pin 11 (GPIO17). Red for power, black for ground, a bright color for signal.
- The relay's three screw terminals, COM, NO, NC, are the switched side. The gate opener lands on COM and NO later. Normally open means the gate stays locked if power drops.
- Installed `python3-gpiozero` and pulsed GPIO17. The relay clicked on and off, only during the script and not at boot, so the board is not active low. Kronk has hands.
- Started on the doorbell button, GPIO27. It has four terminals, two for the switch and two for the 12V LED ring. Found the pairs.
- Leaving the LED ring unconnected, it wants 12V. The button gets a 3D printed housing later.
- Wired the switch contacts to pin 13 (GPIO27) and pin 14 (GND) with M-F jumpers, the male pin twisted around the terminal. Good enough for the desk, soldering comes before anything mounts outside. Pressed the button, DING printed. The doorbell nerve is alive.
- Turns out the building already has a wired doorbell with a button per floor. Option for later: tap that line instead of new wiring, or a separate board for the floors. Those bells often run 8 to 12V AC, so it needs a voltage measurement and an optocoupler before touching GPIO.

Next: wire relay and button into MQTT and Home Assistant.

## 2026-08-09: Headers soldered, everything moved to a hotspot

- Installed Scrypted on the Pi 5. Needed to add its repository first.
- Settled the division of labor: Scrypted is the eyes, the camera lane where speed matters. Home Assistant is the hands, GPIO, automations, and the future lock. The doorbell and lock path will be gate GPIO, MQTT, HA entity, HomeKit.
- Bought the UGreen OTG adapter for the mic.
- Solder hunt: a candidate wire at home would not melt on the iron, so it was not solder. Bread ties are thin steel and do not bond either. A friend had activated flux core solder wire, which is electronics-grade, ideally under 1mm diameter.
- Took the Zero, the iron, and the electronics to the friend's house. Soldered the headers onto the Pi Zero 2 W. First soldering job done.
- Set up the Apple TV there too, connected to my hotspot.
- Reset the Pi 5 for the new network. Ethernet cannot reach a hotspot, so the WiFi details went on a FAT32 USB stick for Home Assistant to import. Reset the Pi Zero 2 W with the hotspot details as well. The resets turned out to be unnecessary, the USB network import also works on an existing install.
- Set up Scrypted on the Pi 5 again.

- Found `http://homeassistant.local:4357`, the observer page that shows Home Assistant's health while the main page is still loading.
- The WiFi config USB has to stay plugged into the Pi 5. Remove it and the network drops.
- Plugged the mic into `kronk-gate` through the OTG adapter. `arecord -l` lists it as card 0, USB PnP Sound Device. Swapped the test tone in [gate/go2rtc.yaml](../gate/go2rtc.yaml) for the mic at `plughw:0,0`.

- Reworked the camera path: removed the Gate camera from Home Assistant. The camera goes through Scrypted only.
- Installed the Scrypted add-on with the repository from its [install guide](https://github.com/koush/scrypted/wiki/Installation:-Home-Assistant-OS), then the `@scrypted/homekit` and `@scrypted/rtsp` plugins.
- Set up the camera in Scrypted from the go2rtc RTSP stream. Skipped the Scrypted Home Bridge and enabled the HomeKit extension on the camera itself, so it pairs in Apple Home as its own accessory. Steps in [home setup](home-setup.md).
- The mic worked but the volume was very low, face against the mic to be heard.
- Raised the ALSA capture gain in `alsamixer` on the USB card, to about 85 since 100 clips, and persisted it with `sudo alsactl store`. `vc4-hdmi` in the device list is the Pi's HDMI output, not the mic.
- Upgraded the video line to 1920x1080 at 25fps, 2Mb/s, with `--intra 100` for a 4 second keyframe interval, matching Scrypted's recommendations. The earlier 1280-wide line came out as 1280x480 with no explicit height.
- Long audio codec fight. Scrypted detected the AAC track as unknown, and HomeKit takes only Opus or PCM-mulaw. Tried an `#audio=opus` transform stream, PCM-mulaw, and Opus in ogg over the exec pipe. Audio piped from `exec:ffmpeg` never registered, the go2rtc info page showed the producer as a bare url with no tracks.
- The fix: go2rtc's native ffmpeg device source, `ffmpeg:device?audio=plughw:0,0#audio=opus#raw=-af volume=24dB`. Native Opus with a 24dB boost. Scrypted now detects h264/opus. Final config in [gate/go2rtc.yaml](../gate/go2rtc.yaml).
- Debugging tools that cracked it: the `info` link on `http://kronk-gate.local:1984` lists every producer, track, and codec, and `journalctl -u go2rtc` shows the spawned ffmpeg's errors.
- Set the Scrypted RTSP parser to Scrypted (TCP). UDP over WiFi drops frames.
- Video in Apple Home is much faster now with the native Opus stream.
- Confirmed: audio plays in Apple Home, the volume is great, and the camera is real time on the home network. Kronk's ears are online.
- Viewing from outside the home network, through the Apple TV hub, is slow, and poor over cellular. Candidate fix for later: a low bandwidth substream in Scrypted, 640x360 around 400Kbps, assigned as the remote stream.
- The Home app showed no Recording section even with iCloud+. HomeKit Secure Video requires the camera to expose a motion sensor, without one Apple hides recording entirely.
- Installed `@scrypted/objectdetector` and `@scrypted/opencv`, and enabled the OpenCV Motion Detection extension on the camera with default settings. Left FFmpeg Audio Detection off, the street would trigger it constantly.
- Reset Pairing, re-added the camera, and picked Stream and Record during setup. Recording options and Face Recognition appeared. HomeKit Secure Video is live. Steps in [home setup](home-setup.md).

The camera pillar is complete: camera, go2rtc, Scrypted, HomeKit, with HKSV clips, face recognition, and live audio.

Next: wire the relay and the doorbell button.

## 2026-08-08: Pi 5 up, running Home Assistant

The indoor unit is alive.

- First shopping trip missed a few things: the soldering iron, the SD cards for the Pi Zeros, and the M-M and M-F jumpers. Went back the next day.
- Flashed the Pi 5 SD card with Home Assistant that night.
- Next day: installed the [Active Cooler](parts/active-cooler.md), plugged into router and power. First boot failed. The outlet was old and faulty and did not deliver enough power, so the setup broke halfway.
- Reflashed, switched to a different outlet and ethernet through a WiFi extender. Worked. Could watch status and logs during setup.
- Finished Home Assistant setup, updated the software, rebooted.
- Set up the Apple HomeKit Bridge and added it to Apple Home. Reset the Apple TV and set it up with my account. It became the Home hub automatically, which gives access to the home over the internet.
- Flashed the SD card for `kronk-gate`, the gate Pi Zero 2 W.
- `kronk-gate` would not come up. The micro USB cables were bad. Swapped them, flashed again, and now it boots and SSH works.
- Installed the [NoIR camera](parts/camera.md) on `kronk-gate`. First time ever connecting a camera, and it was easy: open the connector latches, remove the standard cable, insert the Pi Zero cable, close the latches.
- Verified the sensor with `rpicam-hello --list-cameras`, which printed `imx708`. Took the first photo with `rpicam-still -o first-look.jpg` and pulled it to the Mac with `scp`.
- Streamed the camera with go2rtc: live video in the browser at `http://kronk-gate.local:1984`. Steps in [gate setup](gate-setup.md).
- The stream did not show at first. The config was named `go2rtc.yml`, which go2rtc ignores. Renamed it to `go2rtc.yaml` and it worked.
- Went to hook up the mic and found the micro USB cable will not do. It needs a micro USB male to USB-A female adapter (OTG). Buying a UGreen one next week on a business day.
- Meanwhile, installed ffmpeg and added a 440Hz test tone as a second source in [gate/go2rtc.yaml](../gate/go2rtc.yaml), next to the video.
- The stream looked laggy for a moment. Switched to the WebRTC stream and it is amazingly fast.
- Made go2rtc a systemd service with [gate/go2rtc.service](../gate/go2rtc.service) so it always runs. Enabled it, checked active (running), and the stream survives a reboot.
- Noticed the test tone plays in the MSE stream but the WebRTC stream is silent. WebRTC does not carry AAC audio, it wants Opus. Looking into having go2rtc transcode.
- Added the gate camera to Home Assistant. The go2rtc brand was not in the integration list, so used Generic Camera with `rtsp://kronk-gate.local:8554/gate`. go2rtc serves RTSP on 8554 automatically. Left still image URL and credentials blank, named it Gate. Steps in [home setup](home-setup.md).
- Audio over WebRTC worked fine inside Home Assistant. The silence was only in the browser stream page.
- The RTSP card in Home Assistant lags a few seconds. A WebRTC integration is the later latency fix.
- Configured the HomeKit Bridge camera settings: checked Gate as a native H.264 stream, since rpicam-vid outputs H.264 and the Pi 5 relays instead of transcoding, and checked Gate for audio. Steps in [home setup](home-setup.md).
- A second camera entity named Building Entrance showed up in the HomeKit Bridge list. Figuring out what it is.
- Redid the Apple Home setup from scratch. The Apple TV integration I had added in Home Assistant looped back through the HomeKit Bridge into Apple Home as ghost duplicates of the Apple TV. Removed the Apple TV integration from HA, removed the bridge from the Home app, and deleted all three HomeKit Bridge entries in HA.
- Skipped the bridged device triggers screen while pairing. The doorbell button is not wired yet.
- Added a fresh HomeKit Bridge meant to include only `camera.gate`. The include filter came in empty, so it exported everything and the bridge showed up as Manufacturer Person, serial `person.nizar`. Set the filter to just the camera and it registered properly.
- The camera pairs as its own accessory. Added it as a new service under the bridge, scanned its QR code, and the Gate feed is live in Apple Home on the iPhone.
- No audio in the Apple Home app. HomeKit wants Opus in an SRTP session, and HA transcodes mic audio only when the source track cooperates. The synthetic AAC tone likely gets dropped at that hop, so audio debugging waits for the real mic. If HA cannot do it, Scrypted reads go2rtc directly and handles HomeKit camera audio.

- The Gate camera in Apple Home offers recording profiles for home and away. That is HomeKit Secure Video. It needs iCloud+ and stores clips in Apple's cloud. Going with it: Apple archives, the Pi streams.
- The camera feed in Apple Home is slow. Apple Home does not do WebRTC. HomeKit streams over SRTP, and the extra hop through Home Assistant repackaging the stream adds seconds of startup and latency.
- Decided to move the camera lane to Scrypted. It reads go2rtc directly, serves HomeKit cameras near instantly, and handles HomeKit Secure Video and two-way audio. Home Assistant keeps the automations and the future lock entity.

Next: set up Scrypted, solder the headers on the Pi Zero, then the doorbell button, the relay, the mic, and the speaker.

## 2026-08-08: All parts bought

Everything for the first prototype is in. See [parts](parts.md) and the [bill](bill.csv).

Notes:

- The Pi Zero 2 W with pre-soldered header was out of stock. Bought headerless boards and separate headers. Soldering them is the first job.
- The Pi Zero's camera connector is smaller than standard, so it needs its own [camera cable](parts.md#gate-unit).
- The [NoIR camera](parts/camera.md) has no IR cut filter, so the gate camera works at night.
- The [buck converter](parts/buck-converter.md) will power the gate unit from a 12V supply.

Next: solder headers, flash SD cards, boot both Pis.

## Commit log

2026-08-08 Add project docs: parts, bill, build log, architecture (#1)
    * Add purchase inventory for intercom hardware
    Records all 20 line items purchased so far (24 units, $464.70 total)
    with prices, quantities, and full specifications.
    Claude-Session: https://claude.ai/code/session_01ScG6hesMFmSCk9CMM3Rm2h
    * Restructure repo as documented open-source build
    - Rewrite README as a proper project intro with docs index
    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
    [bill.csv]
2026-08-09 Log build progress: camera live in Apple Home, headers soldered (#2)
    * Log first build session: Pi 5 running Home Assistant
    - Build log: shopping fixups, cooler install, faulty outlet failure,
    successful reboot, HomeKit Bridge, Apple TV as hub, kronk-gate flashed
    - Architecture: software section, Apple Home as UI, kronk-gate hostname
    - README: status update
    * Drop lesson lines from build log, add journal rule
    * Log kronk-gate reflash a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
    [bill.csv]
2026-08-09 Camera through Scrypted, real mic at plughw:0,0 (#3)
    * Swap test tone for real mic at plughw:0,0
    - gate/go2rtc.yaml: mic audio source, card 0 USB PnP Sound Device
    - Gate setup: card 0 examples
    - Home setup: CONFIG USB must stay in, observer page URL
    - Build log: mic detected, WiFi USB constraint
    * Camera goes through Scrypted only, drop HA Generic Camera
    - Home setup: Scrypted add-on install, homekit and rtsp plugins,
    camera as standalone HomeKit accessory
    - Architecture: camera lane bypasses Home Assistant
    - Build log: rework logged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
2026-08-09 Camera pillar complete, relay and doorbell button wired (#4)
    * Final go2rtc config: 1080p video, native Opus mic audio
    Two hours of codec archaeology distilled:
    - gate/go2rtc.yaml: explicit 1920x1080 25fps 2Mb/s with 4s keyframes,
    audio via go2rtc's native ffmpeg device source with 24dB boost
    - Gate setup: ALSA gain, alsactl store, exec-pipe audio dead end,
    go2rtc info page and journalctl debugging, service cockpit commands
    - Home setup: Scrypted stream settings, TCP parser, prebuffer,
    Reset Pairing for the different-home error
    - Build log: the whole fight
    *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
2026-08-21 Gate daemon: doorbell and lock over MQTT (#5)
    * Add kronk-gate daemon: doorbell and lock over MQTT
    GPIO27 button press publishes kronk/doorbell. UNLOCK on
    kronk/lock/set pulses the GPIO17 relay for 3s and publishes
    kronk/lock/state. Release workflow builds arm64 on gate-v* tags.
    Claude-Session: https://claude.ai/code/session_01Vrydu68XfBSdWwHmva3vGs
    * Fix review findings in the gate daemon
    Shutdown waits for an in-flight unlock pulse and forces the relay
    low, so a stop mid-pulse cannot leave the gate energized. Startup
    publishes retained LOCKED to reconcile state after a restart
    mid-pulse. Connect failures now fail fast, systemd retr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
2026-08-21 Harden the gate daemon lock logic (#6)
    Retained UNLOCKs are ignored and cleared, a reconnect cannot replay
    an unlock. A single-slot semaphore replaces the worker machinery:
    shutdown takes the slot, waiting out an in-flight pulse and blocking
    new ones. State follows the relay, the pin actuates before any
    publish and a stuck-on relay is a hard fault that systemd restarts.
    Publishes are bounded at 5s, the doorbell publishes off the GPIO
    event loop at QoS 0. Subscribe runs first on connect. run.sh deleted,
    CI builds gate/ on pull requests, gitignore for build binaries.
    Docs: build log, architecture, README status, MQTT broker and
    entity setup in home-setup.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
2026-08-22 Power corner: LDNIO Z11, Cudy extender, plug-in Pi 5 saddle (#7)
    * Add power corner: LDNIO Z11, Cudy extender, tool-free Pi 5 saddle
    Journal the 2026-08-21 work, add the Z11 to parts and bill, and add
    print/ with the parametric OpenSCAD saddle and rendered STL. The Pi
    mounts without screws: slide-in pockets, guide walls, and a spring
    latch. Flared arm notches nest around the Cudy antennas as lateral
    guides only.
    Claude-Session: https://claude.ai/code/session_01Tz7Awb7SCA4zZsEpKjiMCG
    * Saddle v2 after failed fit: peg mount, short arm, no flares
    The v1 arm ran into the antennas at the Cudy's far end and the edge
    grips hit the power but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
    [bill.csv, pi5-pegs.stl, pi5-saddle.scad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]
2026-08-22 Saddle v13: vented peg sockets, clean arm, stronger pegs (#8)
    * Saddle v13: vented sockets, clean arm, solid-shaft pegs
    The broken pegs were misdiagnosed twice: the Pi's holes were fine, and
    the real killer was air trapped in the blind sockets fighting the
    shaft. The sockets now run through the plate, open at the bottom, so
    the air escapes; the ring stays whole. The zip tie notches are gone,
    the arm is a uniform rectangle. The peg split stops above the shaft,
    which stays solid and takes the press without breaking.
    * Pegs: lengthen shaft to 3.7 into the through soc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
    [pi5-pegs.stl, pi5-saddle-and-pegs.3mf, pi5-saddle.scad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]
2026-08-23 Saddle v14: rivet pegs pass, print project proven, prints get subdirs (#12)
    * Saddle v14: double-ended rivet pegs, clearance bores
    The v13 friction fit was unpressable: printed holes shrink and a
    solid shaft cannot give. The bore becomes a clearance fit with a
    counterbore in the plate's underside; the peg grows a bottom barb
    that clicks into it, flush, while the top barb still clicks through
    the Pi's hole. Two crossed splits give each barb a long flex. Drop
    the stale 3mf until v14 proves out.
    * Add the v14 print project, note the PLA Tough filament
    Co-Authored-By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
    [pi5-pegs.stl, pi5-saddle-and-pegs.3mf, pi5-saddle.scad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]
